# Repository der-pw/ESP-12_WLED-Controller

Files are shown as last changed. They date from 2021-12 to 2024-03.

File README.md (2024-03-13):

# ESP-12_WLED-Controller V1.3 



[English Version below](https://github.com/der-pw/ESP-12_WLED-Controller#english)

---

Designidee eines EPS-12(E/F) basierten NeoPixel (WS2812B, WS2811, SK6812)-Controller speziell für [WLED](https://github.com/Aircoookie/WLED) oder auch Alternativen.

### tl;dr
Ich habe einige Tests zur Stromaufnahme am ESP-32_WLED-Controller durchgeführt. Da beide Controller im Bereich des MOSFET gleich aufgebaut sind, lassen sich die Erkenntnisse übertragen.  
Let's talk about [maximum ratings](https://github.com/der-pw/ESP-32_WLED-Controller/blob/main/maximum_ratings.md)

### Übersicht:
 - [Versionen](https://github.com/der-pw/ESP-12_WLED-Controller#versionen)
 - [Gehäuse](https://github.com/der-pw/ESP-12_WLED-Controller#gehäuse) 
 - [Einstellungen](https://github.com/der-pw/ESP-12_WLED-Controller#einstellungen)
 - [Teileliste](https://github.com/der-pw/ESP-12_WLED-Controller#teileliste)
 - [Anschluss Hinweise](wiring.md) ->

Die Idee war es, einen Controller zu bauen, der mit Pegelwandler arbeitet um das Datensignal, welches der ESP8266 nur mit 3,3V Pegel ausgibt, auf die vom LED-Strip benötigten 5V zu setzen. Gerade bei langen Datenleitungen kann ein 3,3V-Pegel sich schneller "verwaschen". 
Als Levelshifter werwende ich einen **74LVC1G125**.
Zusätzlich kann die Versorgungsspannung für den LED-Strip über einen P-Kanal MOSFET abgeschaltet werden. Auch im ausgeschalteten Zustand verbrauchen die NEOPIXEL-Strips Strom (ca. 1mA/Pixel).   
Praktischerweise bietet WLED hier seit einiger Zeit, die Möglichkeit über einen frei definierten Pin ein "Relay" zu schalten.
Vor dem P-MOSFET sitzt ein weiterer N-MOSFET. Einmal funktioniert dieser als Treiber um den P-MOSFET mit 5V Logikpegel zu schalten und zum anderen als Inverter, damit der Haupt-MOSFET praktisch "active HIGH" am GPIO12 des ESP2866 durchschaltet.

### Versionen:
 - 0.9 erstes Layout veröffentlicht
 - 1.0 kleine Änderungen und Fehler beseitigt
 - - 1.01 C1 und C2 Korrektur der Werte (statt 10nF 10µF) hat keine Auswirkung auf die Platine
 - - 1.1 Gatewiderstand R9 hinzugefügt
 - - 1.2 Gatewiderstand Wert auf 300Ohm geändert
 - - 1.3 Platinenlayout überarbeitet  
 THT-MOSFET entfernt und dafür ...    
 Leiterbahn verbreitert und auf zwei Lagen verteilt  
 zweiter C2 Kondensator  
 Lötjumper unter R6 zum Überbrücken gesetzt  
 zweiter GND Anschluss am Terminal  
 Datenpin von IO4 auf IO2 gelegt [Fehler im Design](https://github.com/der-pw/ESP-12_WLED-Controller/issues/2#issuecomment-1024920433).

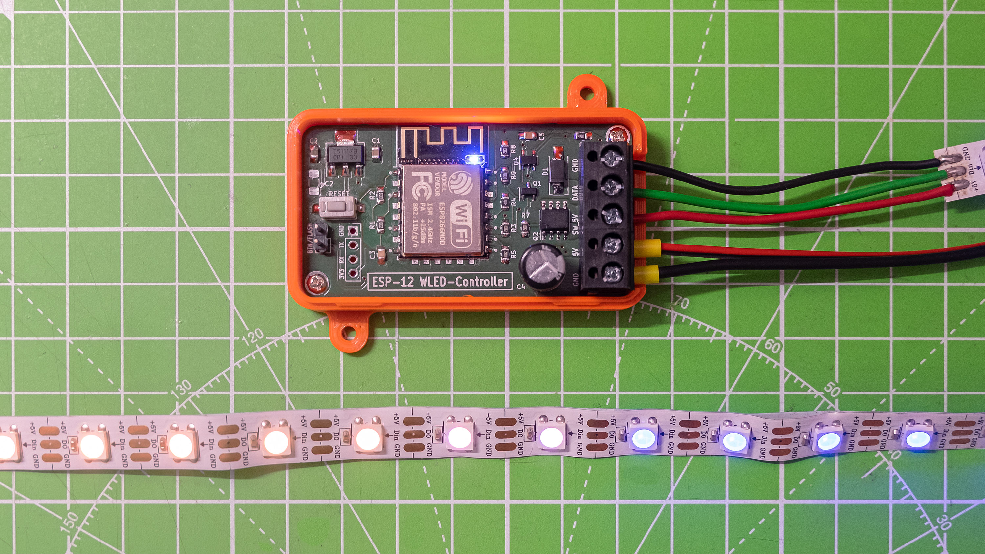
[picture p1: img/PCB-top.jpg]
PCB top


### Gehäuse
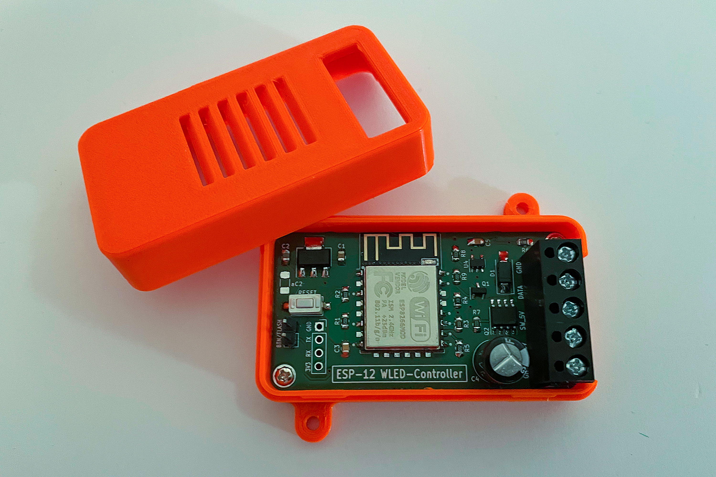
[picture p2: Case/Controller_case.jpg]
PCB case

Es gibt ein simples Gehäuse. 
Die beiden Geäusehälften werden zusammen geklipst.
Die Platine wird mittels 2x5mm Linsenkopfschrauben (Grobgewinde) im Gehäuse befestigt.

### Einstellungen
Die Platine verwendet folgendes Pin-Setting.  
Auf **GPIO0** kann ein externer Button verwendet werden, zum Ein- und Ausschalten und zusätzlich initiert man darüber den Flashvorgang.  
An **GPIO2** hängt das Datensignal und über **GPIO12** wird der MOSFET geschaltet.

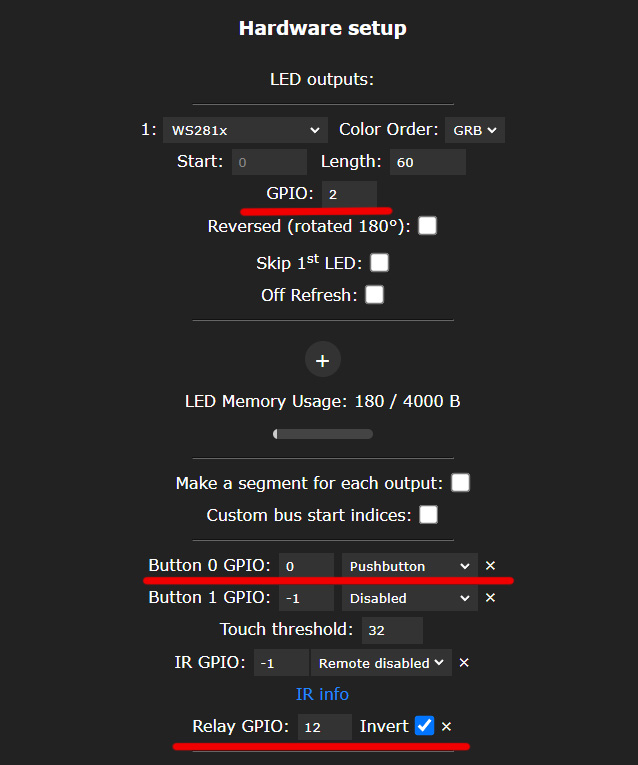
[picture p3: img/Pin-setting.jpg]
Pin-setting


### Teileliste

| Refs | Qty | Component | Description |
| ----- | --- | ---- | --- |
| C1 | 1 | 10µF | 0805 10µF |
| C2 | 1 | 47F | 0805 47µF oder 22µF |
| aC2 | 1 | 100µF | alternativer Footprint in 1206 für größere Kerkos |
| C3, C5 | 2 | 100nF | 0805 100nF |
| C4 | 1 | 1000µF | Elko radial 1000µF 6.3V RM3.5 d=8mm l=11.5mm |
| D1 | 1 | Freilaufdiode | SS14 DO-214 |
| J1 | 1 | Screw_Terminal_01x05 |  |
| J2 | 1 | Conn_01x04_Male | Buchsenleiste RM2.54mm |
| JP1 | 1 | BTN/FLASH | Jumper mit Pinheader RM2.54 |
| JP2 | 1 | Jumper_2_Open | Lötbrücke auf der Rückseite für R6 |
| Q1 | 1 | IRLML6344 | MOSFET N-Kanal 30 V 5A SOT-23 |
| Q2 | 1 | IRF7410 | MOSFET P-Kanal -12 V -16A SO-8 |
| R1, R2, R3, R4, R5, R7, R8 | 7 | 10k | 0805 10kΩ |
| R6 | 1 | 470R | 0805 470Ω |
| R9 | 1 | 300R | 0805 300Ω |
| SW1 | 1 | SW_RST | 6mm x3.5mm Push Button SMD|
| U1 | 1 | TS1117-3.3 | Linearregler 3.3V fix alt. AMS1117-3.3, SOT-223 |
| U2 | 1 | ESP-12F | ESP-12F (ESP8266) Wifi-Modul |
| U4 | 1 | 74LVC1G125 | Single Buffer Gate Tri-State als Logic Level Converter, SOT-23-5 |

Diese Platine kann mit einem [fertigen Binary](https://install.wled.me/) verwendet werden.

## Dankeschön!  

Ein besonderer Dank geht an [Aircoookie](https://github.com/Aircoookie) und allen Beteiligten, die am [WLED](https://github.com/Aircoookie/WLED) Projekt mitarbeiten.

----
## English

### tl;dr
I did some power consumption tests on the ESP-32_WLED controller. Both controllers have the same structure in the MOSFET area, the results can be transferred.  
Let's talk about [maximum ratings](https://github.com/der-pw/ESP-32_WLED-Controller/blob/main/maximum_ratings.md)

----

Design idea of an EPS-12 (E / F) based NeoPixel (WS2812B, WS2811, SK6812) controller especially for WLED or alternatives.

Overview:
 - [Versions](https://github.com/der-pw/ESP-12_WLED-Controller#versions)
 - [Case](https://github.com/der-pw/ESP-12_WLED-Controller#case) 
 - [Settings](https://github.com/der-pw/ESP-12_WLED-Controller#settings)
 - [Parts list](https://github.com/der-pw/ESP-12_WLED-Controller#parts-list)
 - [Connecting Hints](wiring.md) ->

The idea was to build a controller that works with level converters to set the data signal, which the ESP8266 only outputs with a 3.3V level, to the 5V required by the LED strip. Especially with long data lines, a 3.3V level can "fading" more quickly.
As the level shifter I use a **74LVC1G125**.
In addition, the supply voltage for the LED strip can be switched off via a P-Channel MOSFET. Even when switched off, the NEOPIXEL strips consume electricity (approx. 1mA/pixel).
Conveniently, WLED offers the option of switching a "relay" via a freely defined pin. https://github.com/Aircoookie/WLED/issues/631#issuecomment-578551872
Another N-MOSFET sits in front of the P-MOSFET. On the one hand, this works as a driver to operate the P-MOSFET with a 5V logic level and on the other hand as an inverter, so that the main MOSFET switches through practically "active HIGH" on the GPIO12 of the ESP2866.

### Versions:
 - 0.9 first layout published
 - 1.0 minor changes and bugs fixed
 - - 1.01 C1 and C2 wrong Values fixed (10µF instead of 10nF) has no effects of the PCB
 - - 1.1 added gate resistor R9
 - - 1.2 change gate resisitr value to 300Ohm
 - - 1.3 board layout revised  
 THT MOSFET removed and for that...  
 Traces widened and divided onto two layers  
 second alternative C2 capacitor  
 Solder jumper placed under R6 for bridging  
 second GND connector on the terminal.  
 Data pin placed from IO4 to IO2 [Error in design](https://github.com/der-pw/ESP-12_WLED-Controller/issues/2#issuecomment-1024920433). 

PCB top

### Case
PCB case
There is a simple case. The two halves of the housing are clipped together. The circuit board is attached to the housing by means of 2x5mm pan head screws (coarse thread).

### Settings
The board uses the following pin setting.
An external button can be used on GPIO0 to switch it on and off and also to initiate the flash process.
The data signal is connected to GPIO2 and the MOSFET is switched via GPIO12.

Pin-setting

### Parts list

| Refs | qty | components | Description |
| ----- | --- | ---- | --- |
| C1 | 1 | 10µF | 0805 10µF |
| C2 | 1 | 47F | 0805 47µF or 22µF |
| aC2 | 1 | 100µF | alternative footprint in 1206 for larger caps |
| C3, C5 | 2 | 100nF | 0805 100nF |
| C4 | 1 | 1000µF | Capacitor radial 1000µF 6.3V pich3.5 d=8mm l=11.5mm |
| D1 | 1 | Flyback diode | SS14 DO-214 |
| J1 | 1 | Screw_Terminal_01x05 | |
| J2 | 1 | Conn_01x04_Male | Socket strip pitch 2.54mm |
| JP1 | 1 | BTN/FLASH | Jumper with pin header pitch 2.54 |
| JP2 | 1 | Jumper_2_Open | Solder bridge on the back for R6 |
| Q1 | 1 | IRLML6344 | MOSFET N-channel 30V 5A SOT-23 |
| Q2 | 1 | IRF7410 | MOSFET P-channel -12V -16A SO-8 |
| R1, R2, R3, R4, R5, R7, R8 | 7 | 10k | 0805 10kΩ |
| R6 | 1 | 470R | 0805 470Ω |
| R9 | 1 | 300R | 0805 300Ω |
| SW1 | 1 | SW_RST | 6mm x3.5mm Push Button SMD|
| U1 | 1 | TS1117-3.3 | Linear regulator 3.3V fix old. AMS1117-3.3, SOT-223 |
| U2 | 1 | ESP-12F | ESP-12F (ESP8266) Wifi Module |
| U4 | 1 | 74LVC1G125 | Single Buffer Gate Tri-State as Logic Level Converter, SOT-23-5 |

PCB can be used with a [pre compiled binary](https://install.wled.me/).

## Thanks!  

Special thanks to [Aircoookie](https://github.com/Aircoookie) and all the contributors at the [WLED](https://github.com/Aircoookie/WLED) project.

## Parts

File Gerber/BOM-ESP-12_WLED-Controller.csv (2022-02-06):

Comment | Designator | Footprint | LCSC
470R | R6 | R_0805_2012Metric_Pad1.20x1.40mm_HandSolder | C114564
74LVC1G125 | U4 | SOT-23-5 | C12518
IRF7410 | Q2 | SOIC-8_3.9x4.9mm_P1.27mm | C148144
47F | C2 | C_0805_2012Metric_Pad1.18x1.45mm_HandSolder | C16780
10µF | C1 | C_0805_2012Metric_Pad1.18x1.45mm_HandSolder | C1713
10k | R1,R2,R3,R4,R5,R7,R8 | R_0805_2012Metric_Pad1.20x1.40mm_HandSolder | C17414
300R | R9 | R_0805_2012Metric_Pad1.20x1.40mm_HandSolder | C17617
1000µF | C4 | CP_Radial_D8.0mm_P3.50mm | C189254
Flyback diode | D1 | D_SMA_Handsoldering | C2480
SW_RST | SW1 | SW_SPST_CK_RS282G05A3 | C319331
BTN/FLASH | JP1 | PinHeader_1x02_P2.54mm_Vertical | C390678
100nF | C3,C5 | C_0805_2012Metric_Pad1.18x1.45mm_HandSolder | C49678
TS1117-3.3 | U1 | SOT-223-3_TabPin2 | C6186
IRLML6344 | Q1 | SOT-23 | C693370
ESP-12E | U2 | ESP-12E | C82891
Screw_Terminal_01x05 | J1 | TerminalBlock_bornier-5_P5.08mm
100µF | aC2 | C_1206_3216Metric_Pad1.33x1.80mm_HandSolder
Conn_01x04_Male | J2 | PinSocket_1x04_P2.54mm_Vertical
Jumper_2_Open | JP2 | SolderJumper-2_P1.3mm_Open_RoundedPad1.0x1.5mm

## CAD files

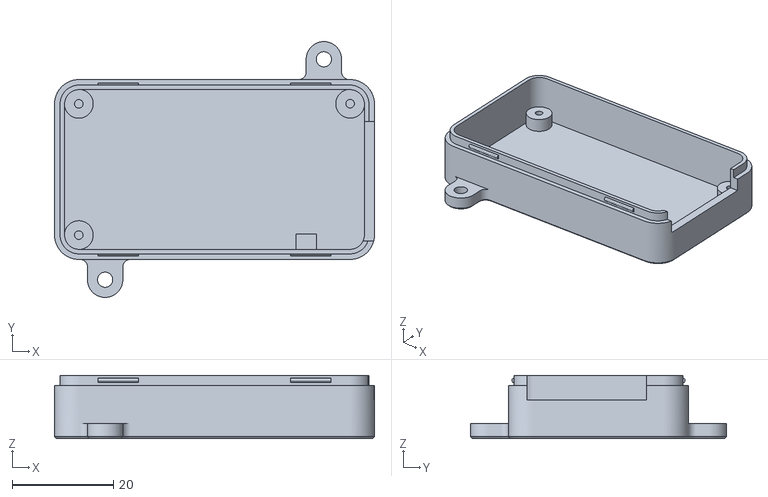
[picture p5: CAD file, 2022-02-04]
Case/WLED-Controller_Case_bottom.stl
63.2 x 50.5 x 12.5

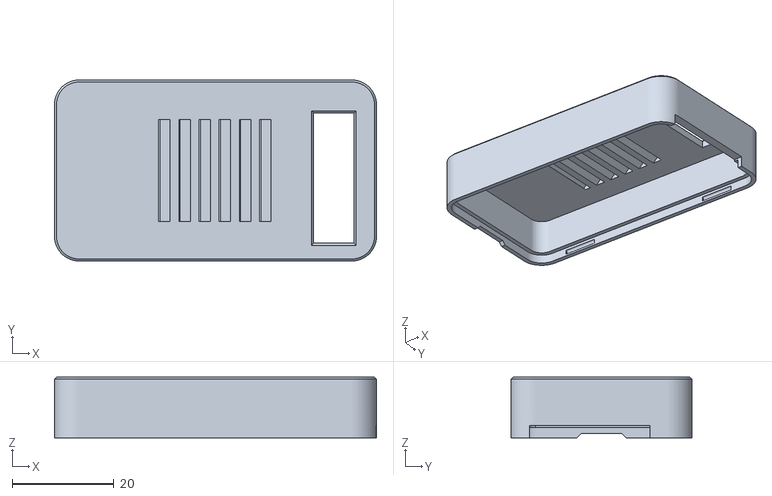
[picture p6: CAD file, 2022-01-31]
Case/WLED-Controller_Case_top.stl
63.2 x 35.5 x 11.9

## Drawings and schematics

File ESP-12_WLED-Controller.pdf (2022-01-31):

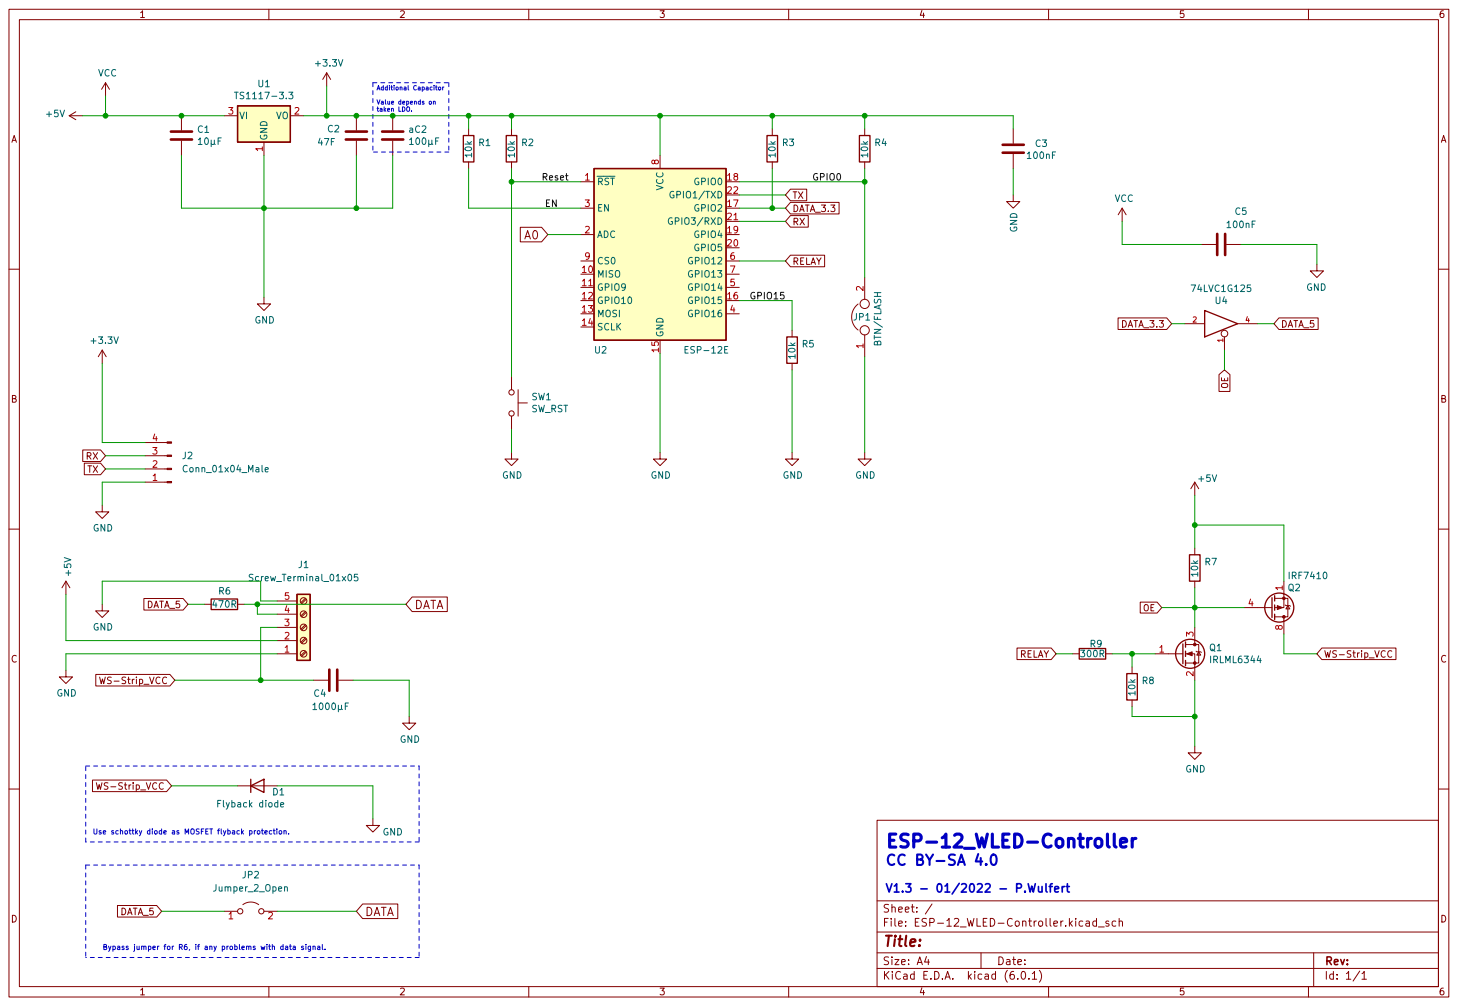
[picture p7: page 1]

1 VO 2 VI 3 U1 TS1117-3.3 GND GND

Additional Capacitor Value depends on

File: ESP-12_WLED-Controller.kicad_sch Sheet: /
Id: 1/1 Title:

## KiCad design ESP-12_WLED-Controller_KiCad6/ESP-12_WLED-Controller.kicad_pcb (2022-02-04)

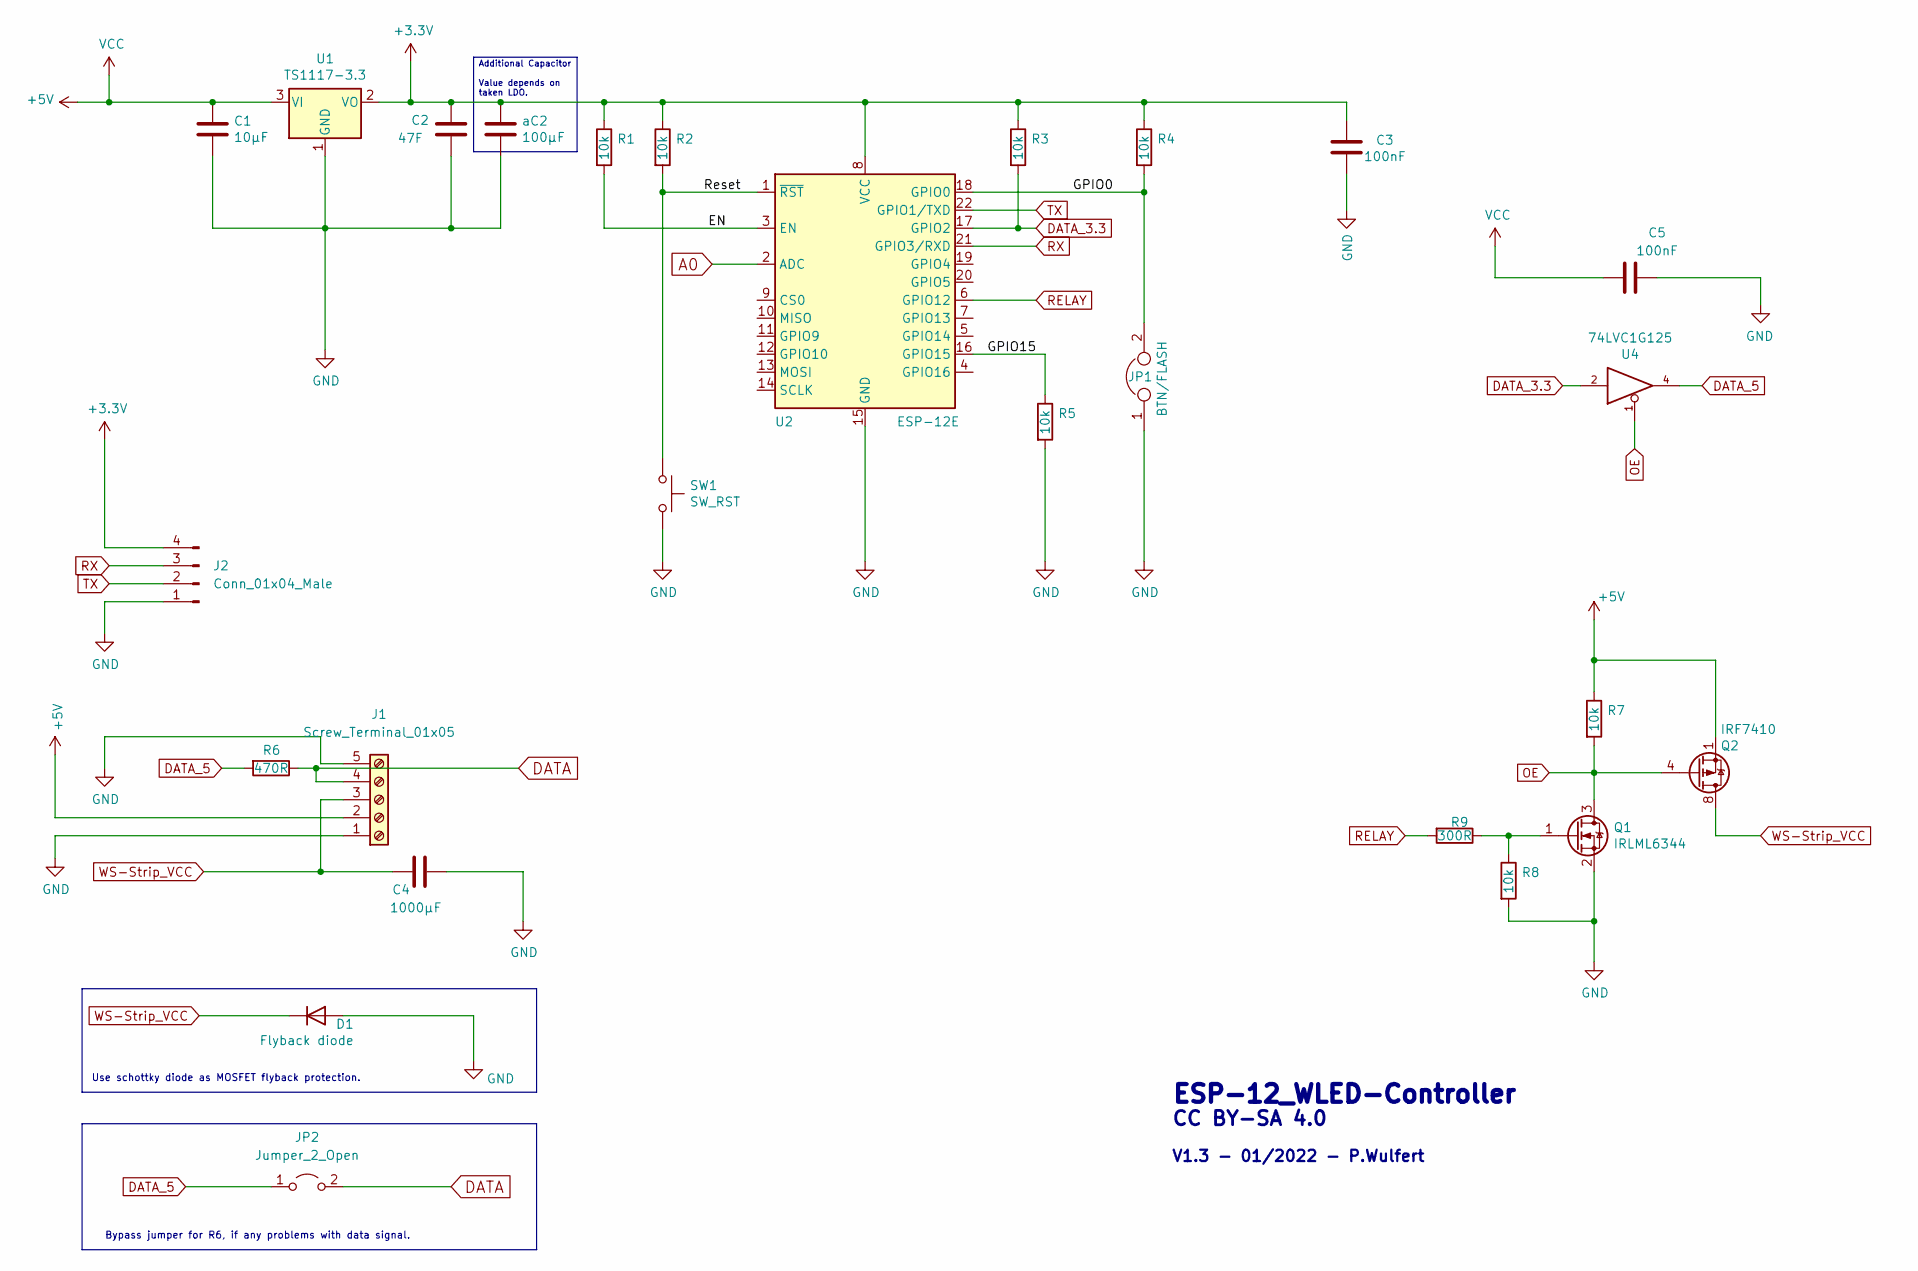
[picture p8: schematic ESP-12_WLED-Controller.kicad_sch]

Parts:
C1: 10µF; C_0805_2012Metric_Pad1.18x1.45mm_HandSolder; LCSC C1713
C2: 47F; C_0805_2012Metric_Pad1.18x1.45mm_HandSolder; LCSC C1713
C3, C5: 100nF; C_0805_2012Metric_Pad1.18x1.45mm_HandSolder; LCSC C49678
C4: 1000µF; CP_Radial_D8.0mm_P3.50mm; LCSC C189254
D1: Flyback diode; D_SMA_Handsoldering; LCSC C2480
J1: Screw_Terminal_01x05; TerminalBlock_bornier-5_P5.08mm
J2: Conn_01x04_Male; PinSocket_1x04_P2.54mm_Vertical
JP1: BTN/FLASH; PinHeader_1x02_P2.54mm_Vertical; LCSC C390678
JP2: Jumper_2_Open; SolderJumper-2_P1.3mm_Open_RoundedPad1.0x1.5mm
Q1: IRLML6344; SOT-23; LCSC C693370
Q2: IRF7410; SOIC-8_3.9x4.9mm_P1.27mm; LCSC C152423
R1, R2, R3, R4, R5, R7, R8: 10k; R_0805_2012Metric_Pad1.20x1.40mm_HandSolder; LCSC C17617
R6: 470R; R_0805_2012Metric_Pad1.20x1.40mm_HandSolder; LCSC C114564
R9: 300R; R_0805_2012Metric_Pad1.20x1.40mm_HandSolder; LCSC C17617
SW1: SW_RST; SW_SPST_CK_RS282G05A3
U1: TS1117-3.3; SOT-223-3_TabPin2; LCSC C410833
U2: ESP-12E; LCSC C82891
U4: 74LVC1G125; SOT-23-5; LCSC C12518
aC2: 100µF; C_1206_3216Metric_Pad1.33x1.80mm_HandSolder

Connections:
+3V3: C2.1, C3.2, J2.4, R1.1, R2.1, R3.1, R4.1, U1.2 (VO), U2.8 (VCC), aC2.1
+5V: C1.1, C5.2, J1.2, Q2.1 (S), Q2.2 (S), Q2.3 (S), R7.1, U1.3 (VI), U4.5 (VCC)
/EN: R1.2, U2.3 (EN)
/GPIO0: JP1.2, R4.2, U2.18 (GPIO0)
/GPIO15: R5.1, U2.16 (GPIO15)
/Reset: R2.2, SW1.1, U2.1 (~RST)
A0: U2.2 (ADC)
DATA: J1.4, JP2.2 (B), R6.1
DATA_3.3: R3.2, U2.17 (GPIO2), U4.2
DATA_5: JP2.1 (A), R6.2, U4.4
GND: C1.2, C2.2, C3.1, C4.2, C5.1, D1.2 (A), J1.1, J1.5, J2.1, JP1.1, Q1.2 (S), R5.2, R8.2, SW1.2, U1.1 (GND), U2.15 (GND), U4.3 (GND), aC2.2
unnamed: Q1.1 (G), R8.1, R9.1
OE: Q1.3 (D), Q2.4 (G), R7.2, U4.1
RELAY: R9.2, U2.6 (GPIO12)
RX: J2.3, U2.21 (GPIO3/RXD)
TX: J2.2, U2.22 (GPIO1/TXD)
WS-Strip_VCC: C4.1, D1.1 (K), J1.3, Q2.5 (D), Q2.6 (D), Q2.7 (D), Q2.8 (D)

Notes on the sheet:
ESP-12_WLED-Controller
Bypass jumper for R6, if any problems with data signal.
Additional Capacitor Value depends on taken LDO.
V1.3 - 01/2022 - P.Wulfert
CC BY-SA 4.0
Use schottky diode as MOSFET flyback protection.

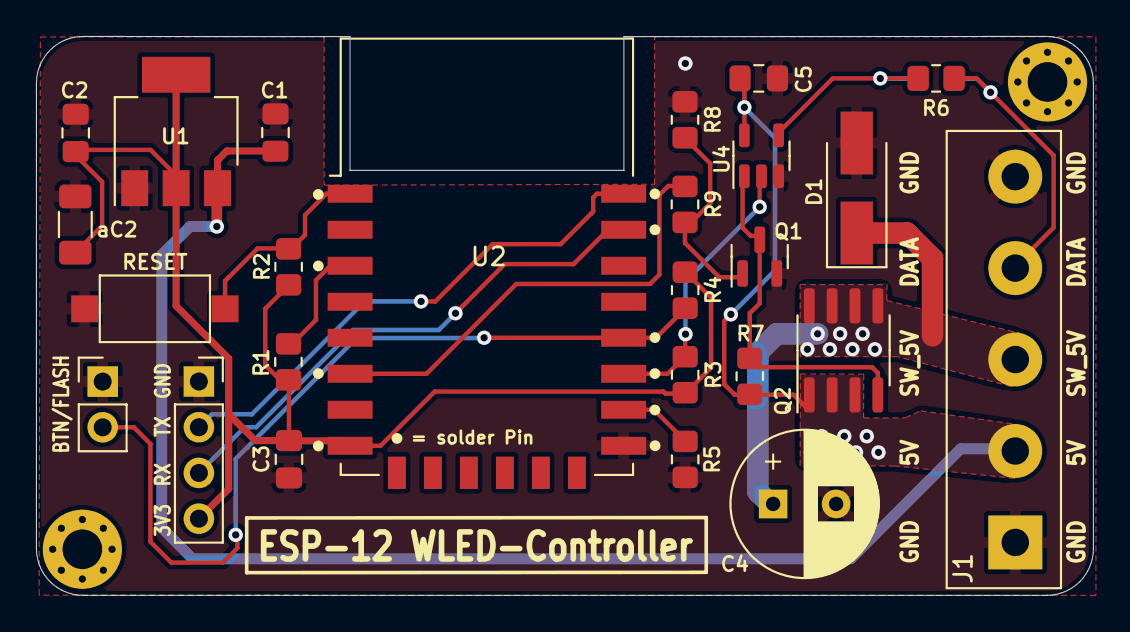
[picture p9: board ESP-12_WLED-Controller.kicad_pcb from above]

Board: 2 copper layers, 58.7 x 31.0 mm, 26 parts (1 on the bottom side), 16 nets.

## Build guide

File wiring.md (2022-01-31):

# ESP-12_WLED-Controller  
[English Version below](#english)

### Anschluss des Serial-UART Konverter (hier FTDI Adapter)
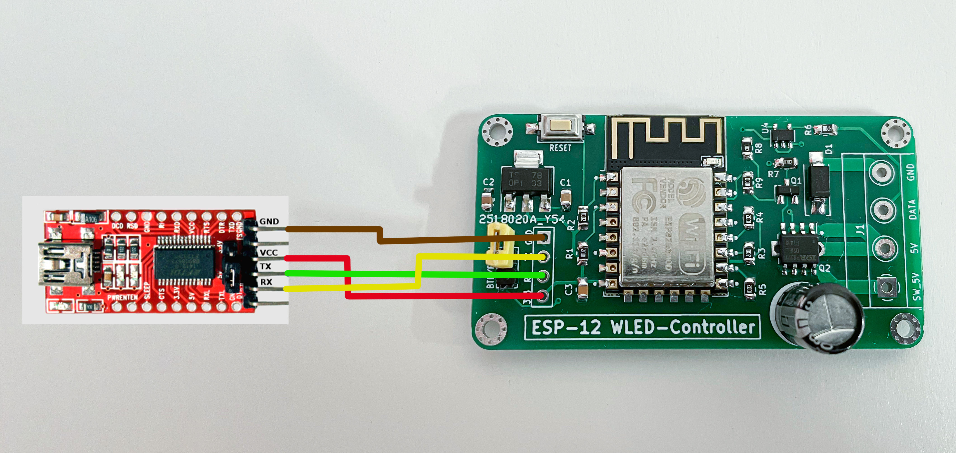
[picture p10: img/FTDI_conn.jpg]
FTDI-Adapter


Der Jumper `BTN/FLASH` ist während des Flashvorganges, mindestens aber bei "Power ON" gebrückt, andernfalls wird der Flashvorgang nicht initialisiert.  

#### Installation von WLED
Die einfachste Möglichkeit, WLED zu installieren ist über die "ESP Web Tools" unter https://install.wled.me/ .  
Dort lassen sich fertige Binaries, ganz einfach über den Browser installieren. Weitere Infos findest du unter: https://kno.wled.ge/basics/install-binary/ .  

##### Doppelfunktion von BTN/FLASH
Später kann im normalen Betrieb von WLED an `BTN/FLASH` ein Taster angeschlossen werden, es besteht die Möglichkeit, den Strip an und aus zu schalten, oder [Makros zu steuern](https://kno.wled.ge/features/macros/). Wichtig hierbei ist, dass man einen NO Taster verwendet, sonst bootet der ESP in die Flash Sequenz.

### Anschluss der Versogungsspannung und des LED-Strips
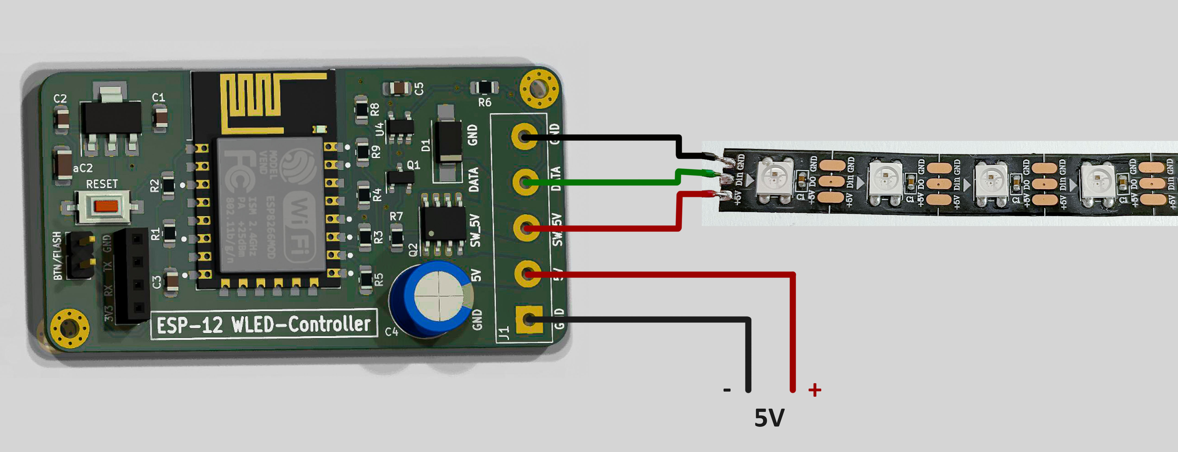
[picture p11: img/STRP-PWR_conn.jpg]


```GND``` für Netzteil- und für Stripanschluss  
```DATA``` Anschluss an die Datenleitung des LED-Strips  
```5V``` Versorgungsspannung vom Netzteil  
```SW_5V``` geschaltete Versorgungsspannung des LED-Strips, wird bei Nichtbenutzen deaktiviert, somit ist der Strip spannungsfrei

---

## English

### Connecting Serial-UART converter (in this case FTDI adapter)
![FTDI-Adapter](img/FTDI_conn.jpg)

The Jumper ```BTN/FLASH``` is bridges during des flashing progress, alternative at start up.  

#### Installation of WLED
The easiest way to install WLED is via the "ESP Web Tools" at https://install.wled.me/ .  
Pre compiled binaries can be easily installed in your browser. You can find more information at: https://kno.wled.ge/basics/install-binary/ . 

##### Double function of BTN/FLASH

Later, during normal WLED operation mode, a button can be connected to `BTN / FLASH`, so it's possible to switch the strip on and off, or [control any macros](https://kno.wled.ge/features/macros/). It's important to use an NO button, otherwise the ESP will boot into the flashing sequence. 

### Connecting power supply and LED strip
![FTDI-Adapter](img/STRP-PWR_conn.jpg)

```GND``` for power supply and for the strip   
```DATA``` data line of the LED strip  
```5V``` supply voltage  
```SW_5V``` switched supply voltage of the LED strip is deactivated when not in use. So the strip is quite turned off

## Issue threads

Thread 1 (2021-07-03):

CPL + BOM Files verfügbar

NemoN, 2021-07-03:
Hallo,

hast du evtl. auch die CPL und BOM Files (Excel Files)?
Dann könnte man die Platine automatisch bestücken lassen.

Grüße
Thomas

der-pw, 2021-07-03:
Hi,

habe ich nicht erstellt.
Ich habe zum Handlöten alle Teile da.
Aber du kannst dich gern dran auslassen. 😉

Schöne Grüße,
Patrick

SoulL3Zz, 2022-01-13:
Hi,

ich habe mal die BOM und CPL Files erstellt.
Leider fehlen aktuell noch die Pinheader und der Reset Button.

[ESP-12_WLED-Controller JLCPCB BOM.xlsx](https://github.com/der-pw/ESP-12_WLED-Controller/files/7865564/ESP-12_WLED-Controller.JLCPCB.BOM.xlsx)
[ESP-12_WLED-Controller JLCPCB CPL.xlsx](https://github.com/der-pw/ESP-12_WLED-Controller/files/7865565/ESP-12_WLED-Controller.JLCPCB.CPL.xlsx)

der-pw, 2022-01-13:
Sehr cool!
Witzigerweise hab ich mir gestern damit auch den Abend vertrödelt.
Die Teilesuche bei JLC ist ja auch nicht gerade mein Freund geworden.
Komplett zerstört hat mich aber die blöde neue Excelversion hier, die einen total blöden CSV-Import hat. 🙄

Für den Taster hatte ich C329185 gefunden.
C4 hatte ich weggelassen. Bestücken die THT?
Die Pinheader könnte man ja auch von Hand löten.

SoulL3Zz, 2022-01-14:
Ja die Suchfunktion bei JLC ist echt nervig. 🙄
Bis ich endlich die fertigen Dateien hatte sind auch Stunden vergangen. Teilweise stimmt die Dokumentation von denen auch nicht. Zum Schluss habe ich mir die Sample Files von denen runtergeladen und geschaut wie das ganze aufgebaut sein muss.

Diese Video fand ich ganz hilfreich: [Link](https://youtu.be/VejO8rDdhzo)

Ah danke, dann werde ich den noch ergänzen.
Ja, die bestücken auch THT: [Link](https://jlcpcb.com/smt-assembly)

Die Pinheader habe ich weggelassen, da Kicad nicht genau die richtige Position ausgibt. JLC benötigt immer die mittigen Koordinaten von den Bauteilen. Kicad gibt mir für die Pinheader nur die Eckkoordinaten aus.

der-pw, 2022-01-16:
Ich habe mal gerechnet. Durch die vielen "extendend" Teile ist das Bestücken schon ein ziemlich teuer Spaß.
Gut, meine ESP12 hab ich nicht so günstig gekauft, wie es JLC anbietet, aber die zusätzlichen Kosten für den Bestücker sind schon happig. Wenn man sich die Teile vorsortiert bekomme ich in ca. 8 Minuten so eine Platine fertig. Gut, das Buffer-Gate hats schon in sich. Also ich werd BOM nicht mehr weiter verfolgen.
Beim nächsten Mal werde ich aber mal eine Schablone mitbestellen.

der-pw, 2022-02-04:
Hab aus den aktuellen Daten nun doch einmal BOM und CPL generiert.
https://github.com/der-pw/ESP-12_WLED-Controller/tree/master/Gerber

SoulL3Zz, 2022-02-06:
Hab gesehen, dass die Position von U1 nicht passt. U1 müsste noch um 180 Grad gedreht werde
[POS-ESP-12_WLED-Controller.csv](https://github.com/der-pw/ESP-12_WLED-Controller/files/8011088/POS-ESP-12_WLED-Controller.csv)
n

Closed 2021-09-20.

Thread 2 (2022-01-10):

automatischer Reboot

SoulL3Zz, 2022-01-10:
Hallo,

ich habe festgestellt, dass wenn ich den Relais-Ausgang Schalte, der ESP-12 sich zurücksetzt und rebootet.

Zunächst habe ich dein Eingang der LED's mit auf dauerhaft +5V gelegt und nicht wie eigentlich vorgesehen auf WS-Strip_VCC.
Das Problem trat seitdem nur noch sporadisch auf.

Zusätzlich habe ich nun den Relais-Ausgang in der Software deaktiviert. Mit dieser Lösung fahre ich bisher ganz gut.
Das Ziel war ja eigentlich, die LED's "komplett" auszuschalten, aber das funktioniert nun nicht mehr.

Daher meine Frage, hatte jemand schon das gleiche Problem?

der-pw, 2022-01-10:
Hi,

ich kann das Problem nicht nachvollziehen.
Die Geräte, die ich alle gebaut habe, und einige andere, von denen ich weiß, laufen alle problemlos.
Ein vernünftiges Foto vom Aufbau könnte hier hilfreich sein. Welche Version von WLED ist installiert?

SoulL3Zz, 2022-01-11:
Hi,

ich habe mittlerweile herausgefunden, dass das Problem nur bei kurzen LED Streifen (45 LED's) auftritt.
Bei längeren LED Streifen (90-170 LED's) ist das Problem nicht vorhanden, allerdings resettet sich der ESP nach gewisser Zeit automatisch.

Ich habe bisher sieben Controller zusammengelötet und bei jedem war das gleiche Problem.
Hier ein kleines Video erstellt, wo man erkennen kann, dass der ESP-12 kurz nachdem das Licht ausgeschaltet ist automatisch rebootet: [Link zum Video](https://youtu.be/A6nTGhMkRpw) (ungefähr bei Sekunde 8)

Es macht auch keinen Unterschied, ob ich die LED's über einen Button oder über die Software ausschalte.

Aktuell ist die Version 0.12.0 installiert. Geflasht wurde über den Webinstaller von WLED.
Die verwendeten LED's sind SK6812 RGBW.

der-pw, 2022-01-11:
Hmm, in der Tat ein sehr merkwürdiges Phänomen.
Ich erkenne einen ESP-12**E**. Könnte das das Problem sein? Ich hatte am Anfang auch E Module und Probleme mit dem Sleep.
Danach habe ich alles F Module verbaut und aus vertrauenswürdiger Quelle. Gib halt reichlich Hinweise auf schlechte, gefälschte Module.
Sag mal, die Flyback-Diode ist aber nicht verkehrt eingelötet? Man sieht es schlecht, aber es hat irgendwie den Anschein auf mich.

SoulL3Zz, 2022-01-11:
Okay, aktuell habe ich auch den ESP-12E verbaut. Werde die Module mal auf den ESP-12F umbauen.

Die Shottky-Diode müsste eigentlich passen, werde ich aber auch nochmal kontrollieren.

der-pw, 2022-01-11:
So sieht sie vom Aufbau her ja gut aus, außer dass ich viel geiziger beim Lötzinn bin. 😁
Porbier das mal aus mit dem Modul, ja. Bin mir fast sicher, dass es danach läuft.
Zumindest hast du die letzte Boardrevision, kann also schonmal nicht am fehlenden Gate-R an Q1 liegen. Den hatte ich dummerweise anfangs vergessen, aber selbst damit laufen bei mir noch welche, ohne Probleme.

Könntest allerdings auch mal die letzte 0.13 beta (https://install.wled.me/v2.htm) testen. Zumindest waren die Probleme mit dem Standby an einem Gerät, das noch mit E-Modul rumliegt, weg.

SoulL3Zz, 2022-01-12:
Danke, hab leider nur noch 1mm Lötzinn, da fällt mir das Dosieren nicht so leicht. 😄

Ich habe den Gatewiderstand allerdings etwas größer gewählt um den Strom zu begrenzen. Aktuell sind 330 Ohm verbaut.

Auf einem Gerät ist jetzt die letzte Version installiert, das Problem mit dem automatischen reboot bleibt aber weiterhin bestehen.

der-pw, 2022-01-12:
> Ich habe den Gatewiderstand allerdings etwas größer gewählt
Danke für den Hinweis, hatte ich lokal sogar schon geändert, aber noch nicht veröffentlicht.

Schauen wir mal, was passiert, wenn du das Modul getauscht hast.

SoulL3Zz, 2022-01-14:
Ich habe nun den ESP-12E gegen einen ESP12-F getauscht und habe weiterhin das Problem, dass er sich beim ausschalten kurzer LED-Streifen zurücksetzt.
Ich schaue auch mal, ob sich das neue Modul immer noch nach einiger Zeit automatisch zurücksetzt. Sollte er das nicht tun, werde ich meine jetzigen Platinen auf den ESP12-F umrüsten.

SoulL3Zz, 2022-01-14:
Ich habe in dem WLED Github Repository ein Issue gefunden, welches einen meiner Fehler beschreibt: [Link](https://github.com/Aircoookie/WLED/issues/2017)

Dann bleibt nur noch die Ursache für das Rebooten nach dem Ausschalten herauszufinden.

der-pw, 2022-01-15:
Könnte das Problem vielleicht auch vom Netzteil ausgelöst werden?
Zeig doch mal bitte ein Foto deines Aufbaus.
Im Video kann man nicht alles erkennen.

SoulL3Zz, 2022-01-15:
Da ich bereits mehrere Netzteile ausprobiert habe, halte ich das für unwahrscheinlich.

Tatsächlich habe ich aber festgestellt, dass das Problem mit dem zurücksetzen nach dem Ausschalten, durch den ESP-12F und der neusten Version (0.13.0-b6) etwas besser geworden ist.

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

SoulL3Zz, 2022-01-15:
![Uploading 412CAC35-07D4-48BF-AC53-9896FA49F01C.jpeg…]()

SoulL3Zz, 2022-01-15:
Hier ein Bild von meinem Aufbau: [Link](https://ibb.co/6BZW8QC)

der-pw, 2022-01-15:
> Da ich bereits mehrere Netzteile ausprobiert habe

Hab ich mir auch schon fast gedacht, wollte aber wenigstens fragen.
Aufbau sieht auch gut aus.

Ich löte morgen mal meine letzte Platine zusammen und werde da mal Tests machen, mit unterschiedlich langen Strips.

der-pw, 2022-01-16:
Ich habe heute nochmal einen V1.1 Controller zusammengelötet. Ist auch mit einem ESP12-F bestückt.
Daran hängt ein 1m langer Strip, also 60 LEDs. Nach einer guten Stunde hat er sich einmal resettet. Da lief er aber auch noch im AP Modus, weil ich zu faul war, das Ding ins WLAN zu hängen. Danach habe ich ihn als Client ins WLAN geholt und jetzt läuft er seit ca. drei Stunden durch. Ob es damit was zu tun hat, kann ich nicht sagen. Hast du WLAN-sleep mal deaktiviert?

SoulL3Zz, 2022-01-16:
Okay, WLAN-Sleep habe ich auch deaktiviert. Hast du das mit einer statischen Farbe oder mit einem Effekt ausprobiert. Ich habe den Eindruck, dass der ESP sich bei den Effekten schneller zurücksetzt, als wie wenn nur eine Farbe leuchtet.

SoulL3Zz, 2022-01-16:
Ich werde jetzt nochmal ein paar Platinen mit dem ESP-12F fertig machen und das ganze weiter beobachten.

SoulL3Zz, 2022-01-18:
So wie es aussieht laufen die Platinen mit dem ESP-12F wesentlich stabiler.
Dieser läuft jetzt seit über einem Tag ohne Probleme und hat sich nicht automatisch zurückgesetzt.

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

der-pw, 2022-01-18:
Hast du ihn mit Effekt durchlaufen lassen oder im Standby?
Meiner hat sich nur kurz nach den Start vorhin einmal resettet und läuft jetzt aber durch.

Ich will am Wochenende mal mit dem Oszi dran.
Vielleicht ribbelt es auch zu heftig hinter dem LDO.
Hast du auch des TS1117 verbaut?

Ich glaube aber nur schwer, dass die Transistrorschaltung dahinter was damit zu tun hat.

SoulL3Zz, 2022-01-20:
Teils/Teils
In letzter Zeit nutze ich die Effekte weniger.
Aber im Standby läuft er auch durch.

Ja, den nutze ich auch.
Das habe ich auch schon überlegt, hab aber leider nicht die Möglichkeit das zu überprüfen.

der-pw, 2022-01-23:
Bei dem Effekt tritt es sehr häufig auf.
`{"on":true,"bri":71,"transition":7,"mainseg":0,"seg":[{"id":0,"start":0,"stop":60,"grp":1,"spc":0,"of":0,"on":true,"bri":255,"cct":127,"col":[[255,0,0],[0,0,0],[0,0,0]],"fx":16,"sx":130,"ix":30,"pal":2,"sel":true,"rev":true,"mi":true},{"stop":0},{"stop":0},{"stop":0},{"stop":0},{"stop":0},{"stop":0},{"stop":0},{"stop":0},{"stop":0},{"stop":0},{"stop":0},{"stop":0},{"stop":0},{"stop":0},{"stop":0}]} `

Ripple war kaum messbar. 38mVpp, die Node-MCU, die ich noch getestet habe, hatte denselben Wert.
Hab in den letzten Tagen, das Board auf den ESP32 umgebaut. Daten liegen schon bei JLC. Im subchannel auf Reddit findet man auch vermehrt Themen, die solch ähnliche Probleme melden. Die Gründe sind ganz verschiedene.

Ne Lösung hab ich also auch nicht mehr, außer möglicherweise das Upgrade auf ESP32.

SoulL3Zz, 2022-01-24:
Okay
Vor einigen Tagen hatte ich hier auch schon ein Issue verlinkt, wo jemand das gleiche Problem hat.

Ich hatte bereits auch schon angefangen die Platine auf den ESP32 umzubauen. 👍
Ist die Platine bei dir breiter geworden? Da der ESP32 ja etwas länger als der ESP12 ist, habe ich schon überlegt, ob ich eine weitere GND Klemme hinzufüge.

Habe allerdings mit der Bestellung gezögert, da der ESP32 teilweise Probleme mit der WLAN Verbindung haben soll.

der-pw, 2022-01-24:
Schau mal hier, das ist das Repo https://github.com/der-pw/ESP-32_WLED-Controller
und ein gerendertes Modell der Platine.
Maße sind jetzt 33x63,4mm ist also breiter und auch etwas länger geworden.
Wie du siehst, habe ich aber auch aus dem Fehler mit dem 2. Masseanschluss gelernt. Ich glaube so ist es jetzt besser, da verschmerze ich 2mm mehr Breite. ;-)

Hab jetzt nochmal WLED selbst kompilliert und so alles rausgeworfen was ich nicht brache Blynk, Alexa usw.
Keine Ahnung ob es was bringt. Ich berichte! :-)

SoulL3Zz, 2022-01-24:
Das sieht doch schonmal vielversprechend aus. 😃
Alternativ könnte man ja überlegen, ob man die Platine auch über einen DC Power Jack versorgt. Bei kürzeren Streifen sind diese vollkommen ausreichend und man benötigt keinen zusätzlichen Adapter. Vorschlagen würde ich eine Hybrid-Lösung, sodass man sich aussuchen kann, welche Variante man nutzt.

der-pw, 2022-01-24:
Dankeschön :-)
DC Jack schreibe ich mal auf meine Liste.

der-pw, 2022-01-26:
Vielleicht noch zu früh zum "feiern" aber ich schreibe es trotzdem mal, weil mich das Thema schon arg beschäftigt.
Zuerst einmal, bin ich sicher, dass einige diese Platine inzwischen nachgebaut haben, und der Fehler eig. schon häufiger hätte bei mir angefragt werden müssen. Irgendwie hats mich jetzt doch gepackt.

Nachdem ich auf meiner Testplatine in den letzten Tagen:
- den Relay-Pin geändert habe (IO13/IO14)
- neben den 100nF noch einen 10µF Kerko vor VCC am ESP gelötet habe
- den Linearregler durch ein komplettes Modul mit AMS1117 getauscht habe
- die Mosfetschaltung komplett totgelegt habe
... habe ich heute mal einen Wemos D1 mini mit zur Arbeit genommen und 8 Stunden problemlos durchlaufen lassen, ohne Reset nix! Nun habe ich das ESP12 Modul vom Wemos runtergelötet und in meine Testplatine eingelötet und anders herum.
Der Wemos mit dem "Absturz-Modul" hat sich nach 23min. resettet. Meine Testplatine mit dem ESP12 aus dem Wemos läuft nun seit über einer Stunde durch.

der-pw, 2022-01-29:
Rätsel gelöst!
https://github.com/Aircoookie/WLED/wiki/FAQ#why-is-gpio2d4-the-default-led-pin

Keine schöne Sache. Hatte mich ja mal für IO4 entschieden, damit die Datenleitung im ausgeschalteten Zustand nicht permanent unter 5V steht. Das war ne blöde Idee. Dass WLED IO2 nimmt, weil dieser Hardware UART ist und der Bit-Banging Treiber dem gnadenlos unterlegen ist, war mir so nicht klar.

Hab jetzt den Trace auf der Unterseite gekappt und den Eingang am Buffer-Gate auf IO2 gelegt.
Damit die Datenleitung im ausgeschalteten Zustand auch LOW steuere ich  OE vom Buffer-Gate über den Pullup vom P-MOSFET mit.

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

SoulL3Zz, 2022-01-30:
Super, Glückwunsch zum gefundenen Fehler 😃 👍
Darauf muss man ja auch erstmal kommen.

Das werde ich bei meine Platinen auch mal ausprobieren

der-pw, 2022-01-31:
Ja, war auch nicht so einfach.
Hab die Platine nun aktualisiert und gleich noch ein paar Änderungen vorgenommen.

Closed 2022-01-31.

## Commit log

2021-06-21 add IRF7410 Power MOSFET
    [ESP-12_WLED-Controller.kicad_pcb, ESP-12_WLED-Controller.sch]
2021-06-22 LLC changes
    [ESP-12_WLED-Controller.kicad_pcb, ESP-12_WLED-Controller.sch]
2021-06-23 some changes
    single Terminal-Block
    parts clean up
    edit footprints for handsolder
    [ESP-12_WLED-Controller.kicad_pcb, ESP-12_WLED-Controller.sch]
2021-06-24 some PCB updates
    [ESP-12_WLED-Controller.kicad_pcb]
2021-07-03 Update to V1.0
    clean schematic
    add description
    TX <-> RX
    [ESP-12_WLED-Controller.kicad_pcb, ESP-12_WLED-Controller.sch]
2021-07-03 add simple Case
    [WLED-Controller_Case_bottom.stl, WLED-Controller_Case_top.stl]
2021-07-03 update schematic
    [ESP-12_WLED-Controller.sch]
2021-11-07 V 1.01
    update schematic to 1.01
    [ESP-12_WLED-Controller.sch]
2021-12-12 Upgrade to V1.1
    Added R9 gate resistor to PCB
    [ESP-12_WLED-Controller.kicad_pcb, ESP-12_WLED-Controller.sch]
2021-12-26 Update wiring.md
    add some informations
2022-01-06 Upgrade to KiCad6
    [ESP-12_WLED-Controller.kicad_pcb, ESP-12_WLED-Controller.kicad_sch, ESP-12_WLED-Controller.sch]
2022-01-12 V1.2
    change Gate Resistor to 300 Ohm
    [ESP-12_WLED-Controller.kicad_sch]
2022-01-14 Update to V2.0
    [ESP-12_WLED-Controller.kicad_pcb, ESP-12_WLED-Controller.kicad_sch, ESP-12_WLED-Controller.sch]
2022-01-31 Update to V1.3
    [BOM-ESP-12_WLED-Controller.csv, ESP-12_WLED-Controller.kicad_pcb, ESP-12_WLED-Controller.kicad_sch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]
2022-02-04 update
    - Pinsetting
    - Case bottom
    - Gerbers
    [ESP-12_WLED-Controller.kicad_pcb, ESP-12_WLED-Controller.kicad_sch, WLED-Controller_Case_bottom.stl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]
2022-02-05 Update PCB-top.jpg
    replace rendering
2022-02-06 update BOM
    [BOM-ESP-12_WLED-Controller.csv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]

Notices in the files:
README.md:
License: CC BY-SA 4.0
